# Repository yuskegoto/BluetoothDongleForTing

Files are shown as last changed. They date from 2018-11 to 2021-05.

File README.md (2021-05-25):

# Bluetooth Dongle for Ting
This is an attempt to give bluetooth HID ability to the OiD reading pens. I named this repo as "dongle", however the device is quite big, as you won't call it dongle. Well, who cares!
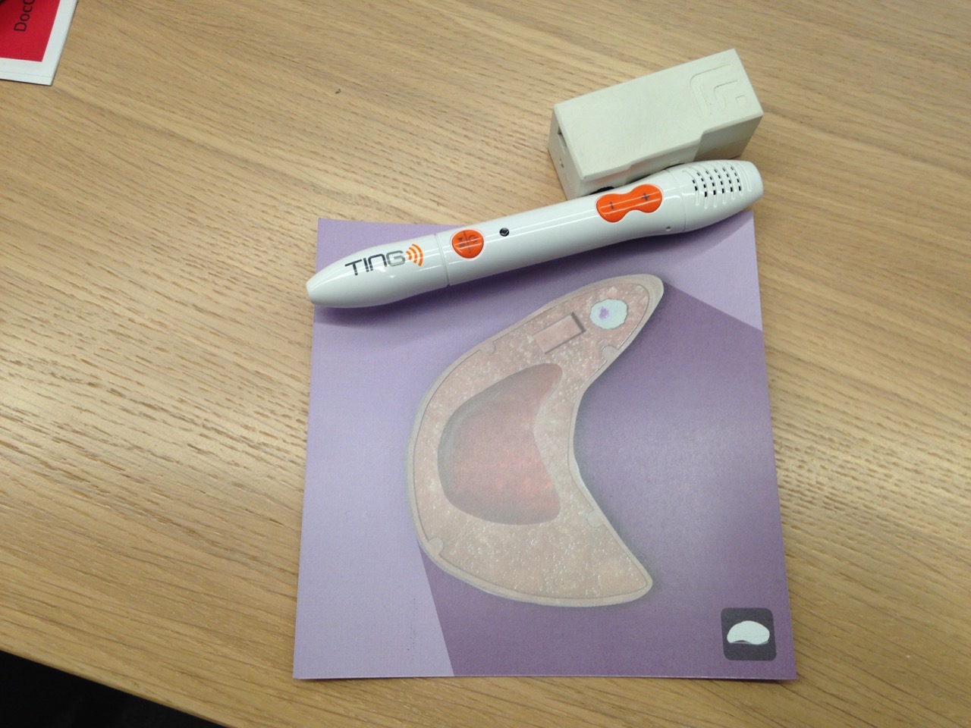
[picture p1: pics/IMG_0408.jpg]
Product with OiD-printed card


## Generating OiD
I used the OiD generator called (Tingeltangel.)[https://github.com/Martin-Dames/Tingeltangel]
Java binary can be also found (here)[https://www.ting-el-tangel.de/doku.php?id=download] Please be aware that most of the information is avaiable only on German. However the app is straight forward, probably you can use it without much knowledge about German.

## System
As shown here, a letter is modulated to simple sound pulse like morse signal based on ascii code binary bits. The processor (ATTiny45) samples the sound burst and encodes the sampled bits based on simple packet format with header and footer.
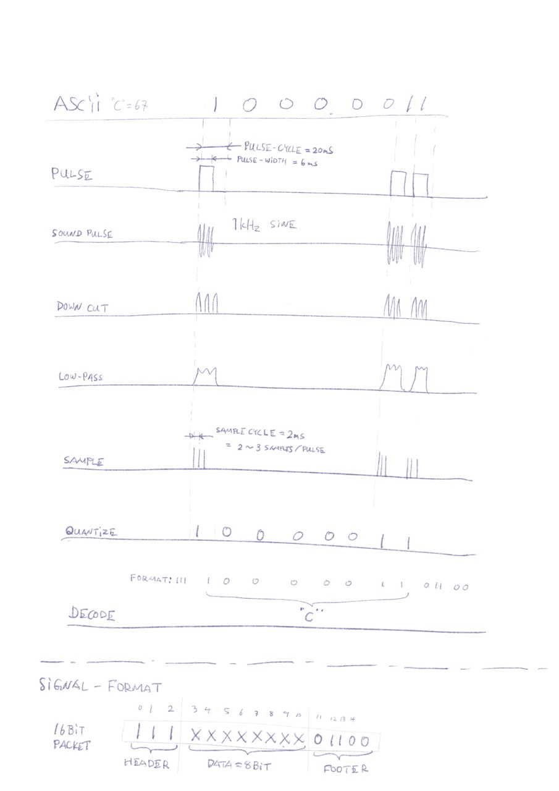
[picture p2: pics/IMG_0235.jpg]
Very rough algorithm visualsation


The sound files are stored to the Ting device as wav or MP3. When user reads a OiD printed surface with the pen, Ting plays the corresponding sound file.
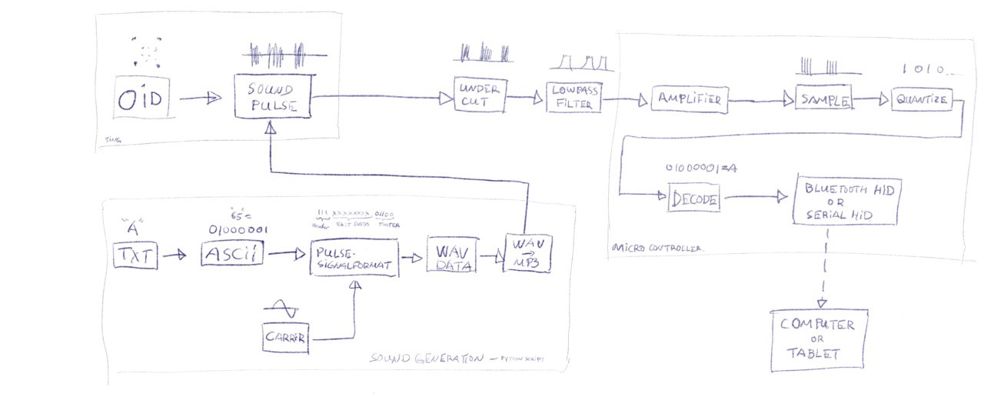
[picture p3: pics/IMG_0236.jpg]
Process Diagram


The daata is extracted using footer and header. No parity bit is used. Just simple (and primitive) bit alignment.
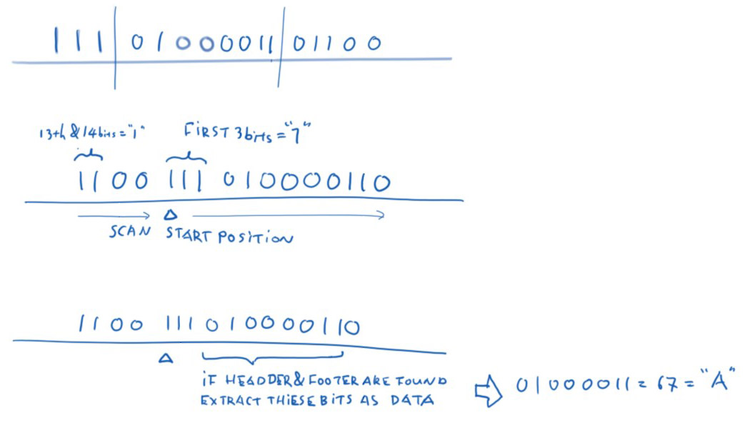
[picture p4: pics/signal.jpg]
Signal Processing


## Circuit
The circit is extremely simple, using only one OP amp and an ATTiny controller.
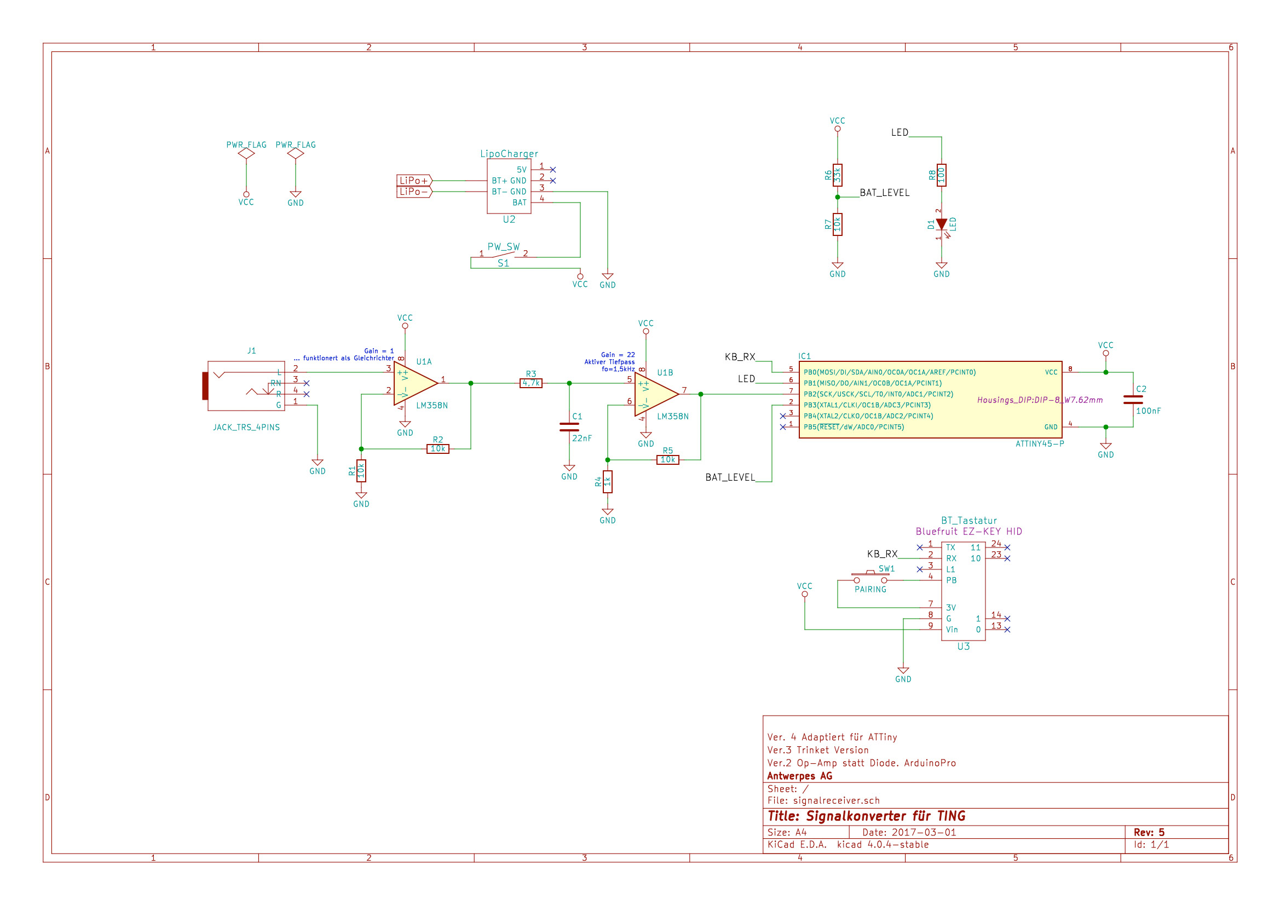
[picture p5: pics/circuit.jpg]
Circuit Diagram

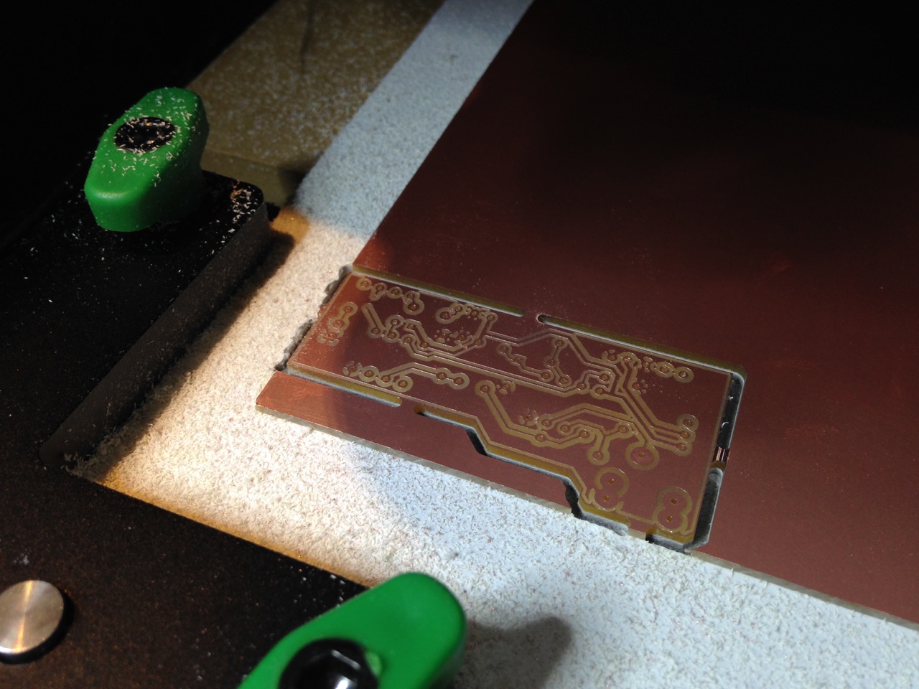
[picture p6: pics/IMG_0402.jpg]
Milling PCB

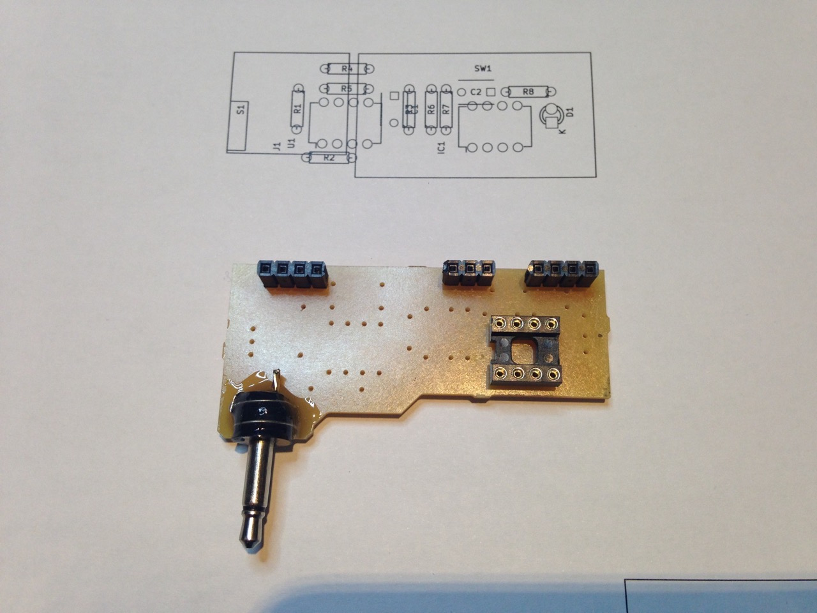
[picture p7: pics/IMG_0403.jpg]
Mounting Components

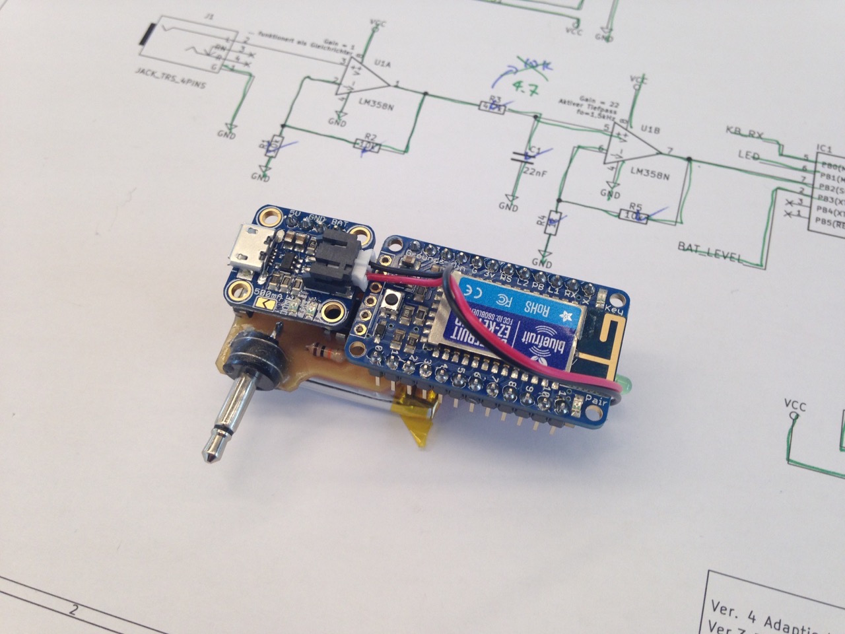
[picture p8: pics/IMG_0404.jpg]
Mounting Modules

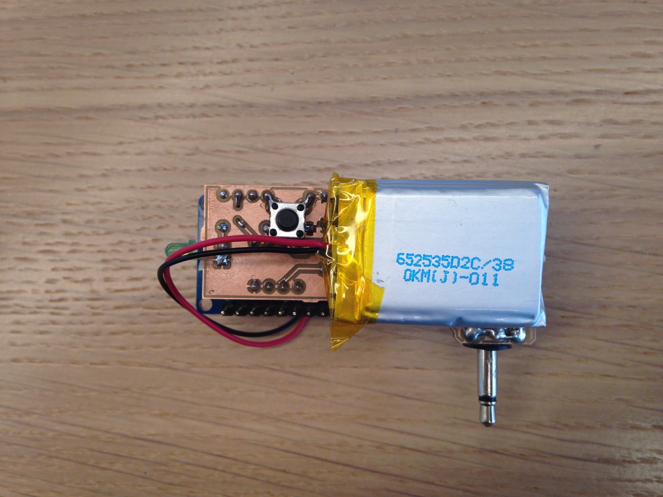
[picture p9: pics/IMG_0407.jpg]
Whole assembly


## Reference
There is also a thread about Ting reverse engineering in mikrocontroller.net. The thread is also in German too.
(https://www.mikrocontroller.net/topic/214479)[https://www.mikrocontroller.net/topic/214479]

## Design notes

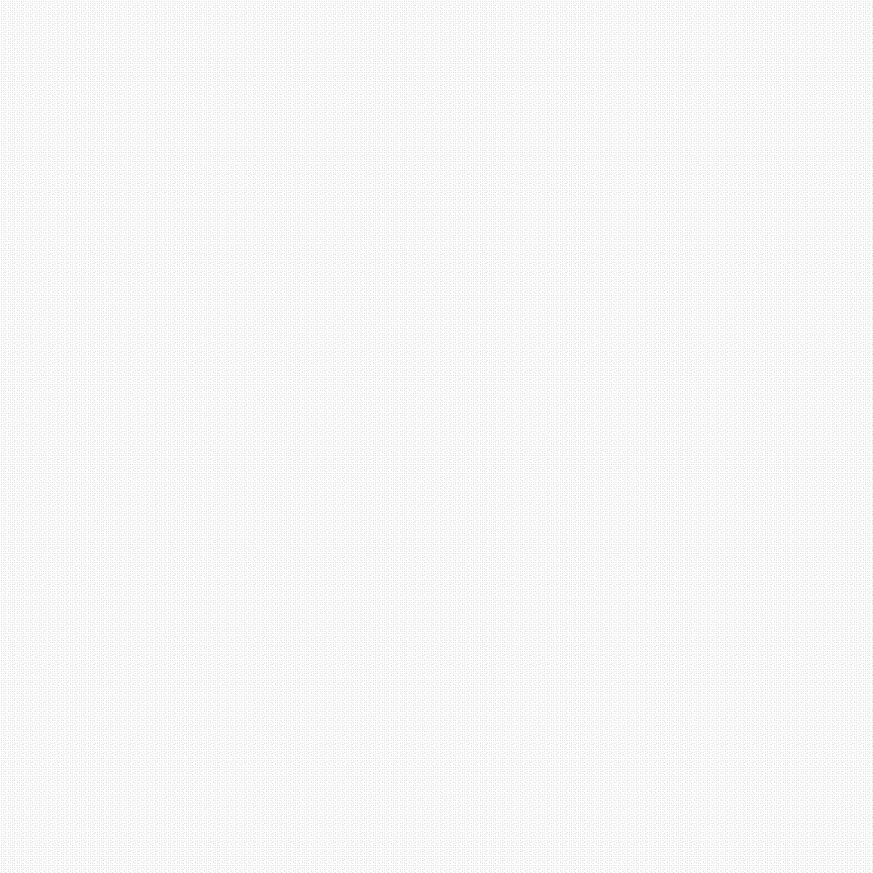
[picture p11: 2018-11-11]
tingCode/OiDs/activation.png

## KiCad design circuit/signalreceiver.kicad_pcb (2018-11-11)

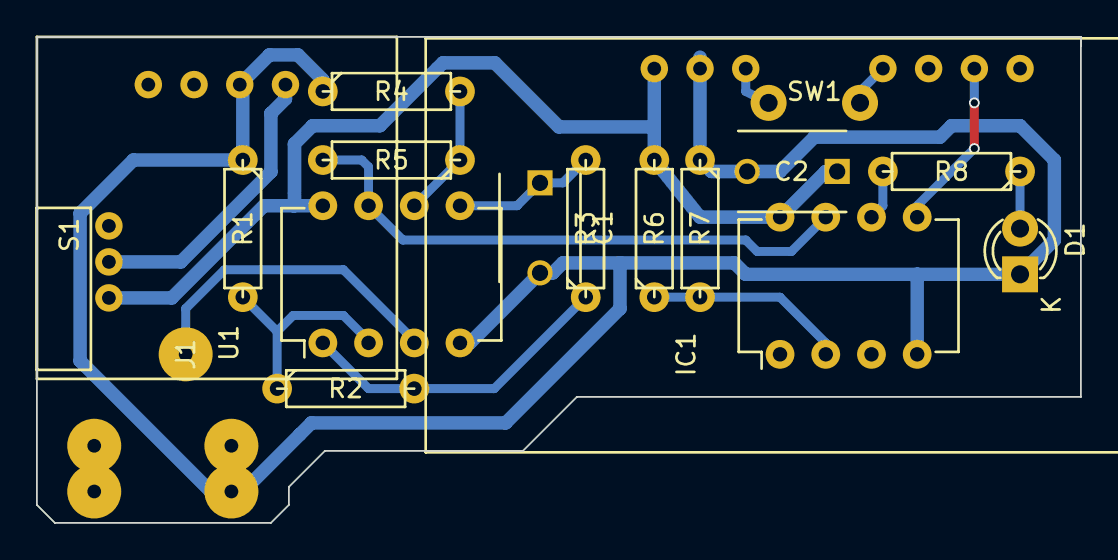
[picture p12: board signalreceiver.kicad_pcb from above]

Board: 2 copper layers, 58.0 x 27.0 mm, 18 parts (0 on the bottom side), 15 nets.

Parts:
C1: 22nF; C_Disc_D6_P5
C2: 100nF; C_Disc_D6_P5
D1: LED; LED-3MM
IC1: ATTINY45-P; DIP-8_W7.62mm
J1: JACK_TRS_4PINS; Audio_Klinke
R1, R2, R5, R7: 10k; R3-LARGE_PADS
R3: 4,7k; R3-LARGE_PADS
R4: 1k; R3-LARGE_PADS
R6: 33k; R3-LARGE_PADS
R8: 100; R3-LARGE_PADS
S1: PW_SW
SW1: PAIRING; PUSH_SW
U1: LM358N; DIP-8_W7.62mm
U2: LipoCharger; LiPoCharger
U3: BT_Tastatur; Bluefruit_EZ-KEY_HID

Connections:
/BAT_LEVEL: IC1.2, R6.1, R7.2
/KB_RX: IC1.5, U3.2
/LED: IC1.6, R8.2
GND: C1.2, C2.2, D1.1, IC1.4, J1.1, R1.1, R4.1, R7.1, U1.4, U2.3, U3.8
unnamed: C1.1, R3.2, U1.5
unnamed: D1.2, R8.1
unnamed: IC1.7, R5.2, U1.7
unnamed: J1.2, U1.3
unnamed: R1.2, R2.1, U1.2
unnamed: R2.2, R3.1, U1.1
unnamed: R4.2, R5.1, U1.6
unnamed: S1.2, U2.4
unnamed: SW1.1, U3.7
unnamed: SW1.2, U3.4
VCC: C2.1, IC1.8, R6.2, S1.1, U1.8, U3.9

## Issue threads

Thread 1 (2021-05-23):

How did you generate the OID codes?

kargeor, 2021-05-23:
I see the output files but no script to generate them.

yuskegoto, 2021-05-24:
Hi kargeor!
You are right, I haven't put any info about generating OiD. I'm going to add some info soon. It's been while since I poked around the Ting stuff, that I can barely remember anything... Yes, I used the OiD generator called Tingeltangel.
[https://github.com/Martin-Dames/Tingeltangel](https://github.com/Martin-Dames/Tingeltangel)
Java binary can be also found here
[https://www.ting-el-tangel.de/doku.php?id=download](https://www.ting-el-tangel.de/doku.php?id=download)
The thing is that the UI of the app is only German. However the app is straight forward, probably you can use it without much knowledge about German.

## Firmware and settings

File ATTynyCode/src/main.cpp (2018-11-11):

#include <Arduino.h>

#define LED 13
#define SIGNAL_PIN 2
#define REF_OUT 3

#define SAMPLE_CYCLE 2 //ms
#define PULSE_CYCLE 16  //ms
#define PULSE_LENGTH 6 / SAMPLE_CYCLE   //Signal pulse width (6ms) in sample count
#define SIGNAL_LENGTH PULSE_CYCLE / SAMPLE_CYCLE

#define PACKET 16

//#define SERIAL_DEBUG
//#define KEYBOARD
#define BTKEY

#ifdef KEYBOARD
  #include "Keyboard.h"
#endif

uint32_t sampleTimer;
bool buffer[SIGNAL_LENGTH];
uint8_t bufPointer;

uint8_t sampleCounter = 0;

bool packet[PACKET];
uint8_t packetPointer = 0;

uint8_t byteSignal, byteSignalPointer;
uint8_t adjustCycle = 0;

bool sentKey = false;

void setup(){
  #ifdef SERIAL_DEBUG
    Serial.begin(9600);
  #endif

  #ifdef BTKEY
    Serial.begin(9600);
  #endif

  #ifdef KEYBOARD
    Keyboard.begin();
  #endif

  pinMode(LED, OUTPUT);
  pinMode(SIGNAL_PIN, INPUT_PULLUP);
  pinMode(REF_OUT, OUTPUT);

  digitalWrite(LED, LOW);
  digitalWrite(REF_OUT, LOW);

  sampleTimer = millis();
  bufPointer = 0xFF;

}

bool readSignal(){
  bool sample = false;
  uint32_t loop = millis() - sampleTimer;
  if(loop >= SAMPLE_CYCLE){
    sample = true;

    bufPointer ++;
    if(bufPointer >= SIGNAL_LENGTH) bufPointer = 0;

    if(digitalRead(SIGNAL_PIN) == HIGH){
      buffer[bufPointer] = true;
      digitalWrite(LED, HIGH);
      digitalWrite(REF_OUT, HIGH);
    }
    else{
      buffer[bufPointer] = false;
      digitalWrite(LED, LOW);
      digitalWrite(REF_OUT, LOW);
    }
    sampleTimer = millis();
  }
  return sample;
}

uint8_t getValue(){
  uint8_t value = 0xFF;
  //if signal rise is detected or reached one cycle count
  if((bufPointer != 0 && buffer[bufPointer] && !buffer[bufPointer-1])
|| (bufPointer >= SIGNAL_LENGTH - 1)){

    uint8_t signalCounter = 0;
    for(uint8_t i = 0; i < SIGNAL_LENGTH; i ++){
      if(buffer[i]) {
        if(i != bufPointer) signalCounter ++;
      }
    }

    //if signal "1" is detected
    if(signalCounter >= PULSE_LENGTH - 1){
      value = 1;
    }
    else value = 0;

    bufPointer = 0xFF;
  }
  return value;
}

uint8_t findStartPoint(){

  uint8_t table[PACKET];
  uint8_t startPt = 0xFF;

  for(uint8_t i = 0; i < PACKET ; i ++){
    for(uint8_t j = 0; j < PACKET ; j ++){
      if((i + j) < PACKET) table[j] = i + j;
      else table[j] = i + j - PACKET;
    }

    if(packet[table[0]] && packet[table[1]] && packet[table[2]]){
      for(uint8_t j = 0; j < PACKET ; j ++){
    }
      if(!packet[table[11]] && packet[table[12]] && packet[table[13]]){
        startPt = i;
        i = PACKET;
      }
    }
  }
  return startPt;
}

char getChar(uint8_t pointer){
  char extChar = 0;
  uint8_t table[PACKET];
  for(uint8_t j = 0; j < PACKET ; j ++){
    if((pointer + j) < PACKET) table[j] = pointer + j;
    else table[j] = pointer + j - PACKET;
  }

  for(uint8_t i = 0; i < 8 ; i ++){
    if(packet[table[i + 3]]){
      extChar |= B1 << (7 - i);
    }
  }
  return extChar;
}

void typeKey(char key){
  if(key != 0){
    if(!sentKey){
      #ifdef KEYBOARD
        Keyboard.print(key);
      #endif

      #ifdef BTKEY
        Serial.write(key);
      #endif

    sentKey = true;
    }
  }
  else sentKey = false;
}

void loop(){
  char sentCharacter = 0;

  if(readSignal()){
    uint8_t val = getValue();

    // if value is detected
    if(val <= 1){
      //if it is adjust cyle,waste the value
//      if(adjustCycle != 0) adjustCycle --;
//      else{
        packetPointer ++;
        //if signal "1" is detected
        if(val == 1) packet[packetPointer] = true;
        //if signal is "0"
        else if(val == 0) packet[packetPointer] = false;
//      }

      //when the packet buffer is full
      if(packetPointer >= PACKET - 1){

        uint8_t startPoint = findStartPoint();

        if(startPoint != 0xFF){
          sentCharacter = getChar(startPoint);
//          if(startPoint != 0){
//            adjustCycle = PACKET - 1 - startPoint;
//          }
        }

        for(uint8_t i = 0; i < PACKET ; i ++){
          if(packet[i]){
            #ifdef SERIAL_DEBUG
              Serial.print(0x1);
            #endif
          }
          else {
            #ifdef SERIAL_DEBUG
              Serial.print(0x0);
            #endif
          }
          #ifdef SERIAL_DEBUG
            Serial.print(" ");
          #endif
        }

        #ifdef SERIAL_DEBUG
          Serial.print("chr:");
          Serial.print(sentCharacter);
          Serial.println();
        #endif

        #ifdef KEYBOARD
          typeKey(sentCharacter);
        #endif

        #ifdef BTKEY
          typeKey(sentCharacter);
        #endif

        //clear up all
        for(uint8_t i = 0; i < PACKET ; i ++){
          packet[packetPointer] = false;
        }
        packetPointer = 0xFF;
      }
    }
  }
}
